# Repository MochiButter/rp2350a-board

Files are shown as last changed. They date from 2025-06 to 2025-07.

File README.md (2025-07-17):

# rp2350a-board
A simple development board featuring the rp2350a microcontroller.

## Changes from the Pico 2

- PICO_DEFAULT_LED_PIN is now IO15
- Flash size increased to 128Mbit
- ESD protection on the usb data wires
- A reset button
- An LDO voltage regulator
- USB-C receptacle

`blink` and `hello_usb` of the examples worked on the board as expected.

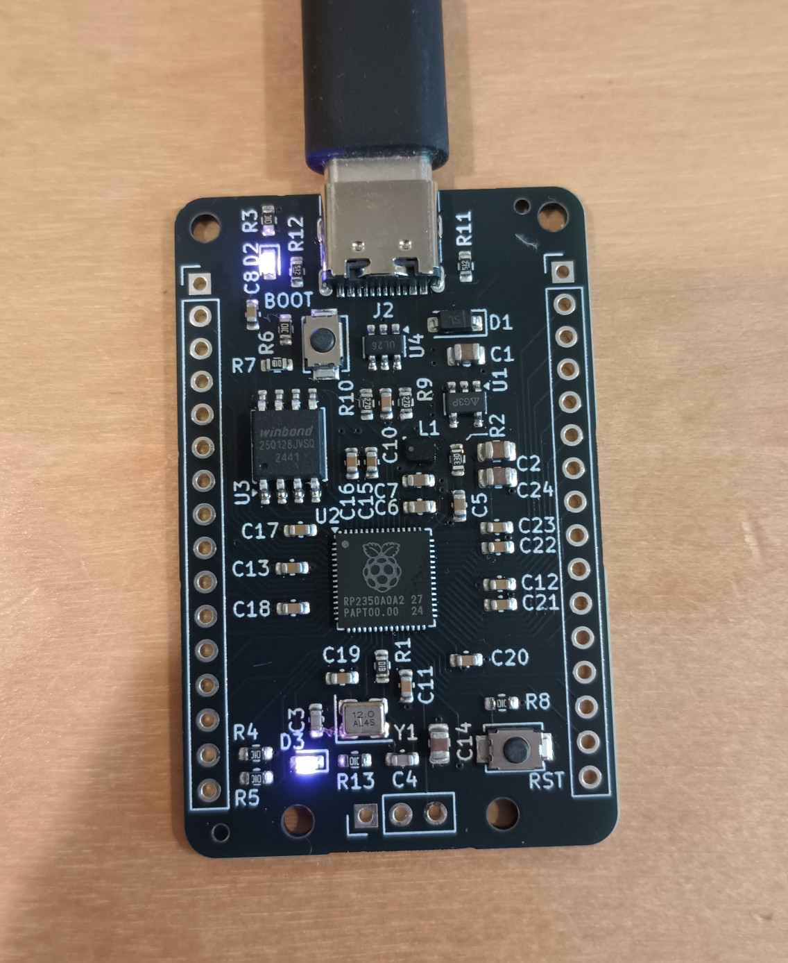
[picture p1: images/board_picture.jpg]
A photo of the board


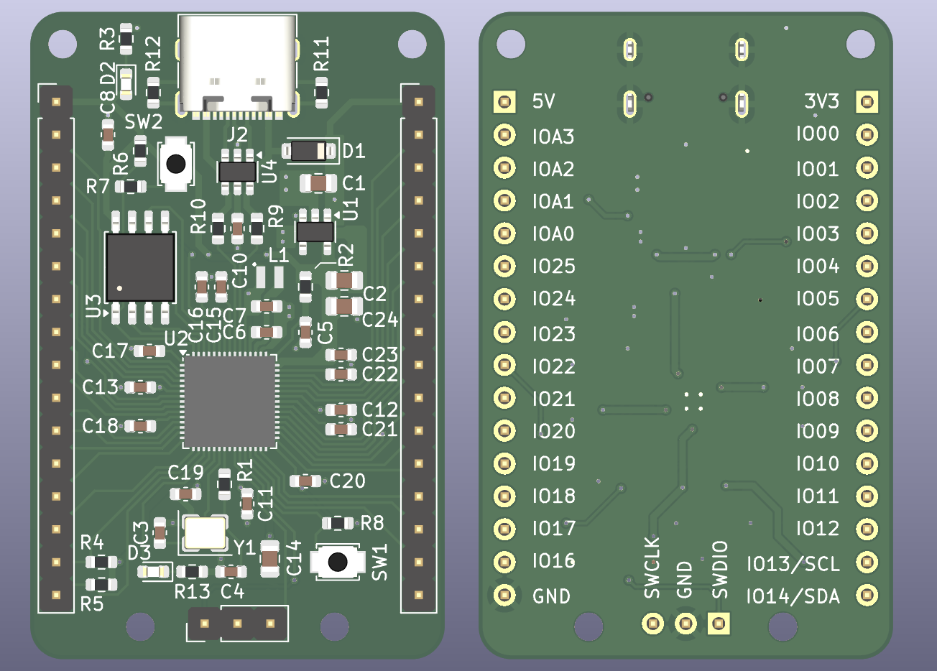
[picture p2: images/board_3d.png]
3D render of the board


Licensed under CERN-OHL-P v2 or later

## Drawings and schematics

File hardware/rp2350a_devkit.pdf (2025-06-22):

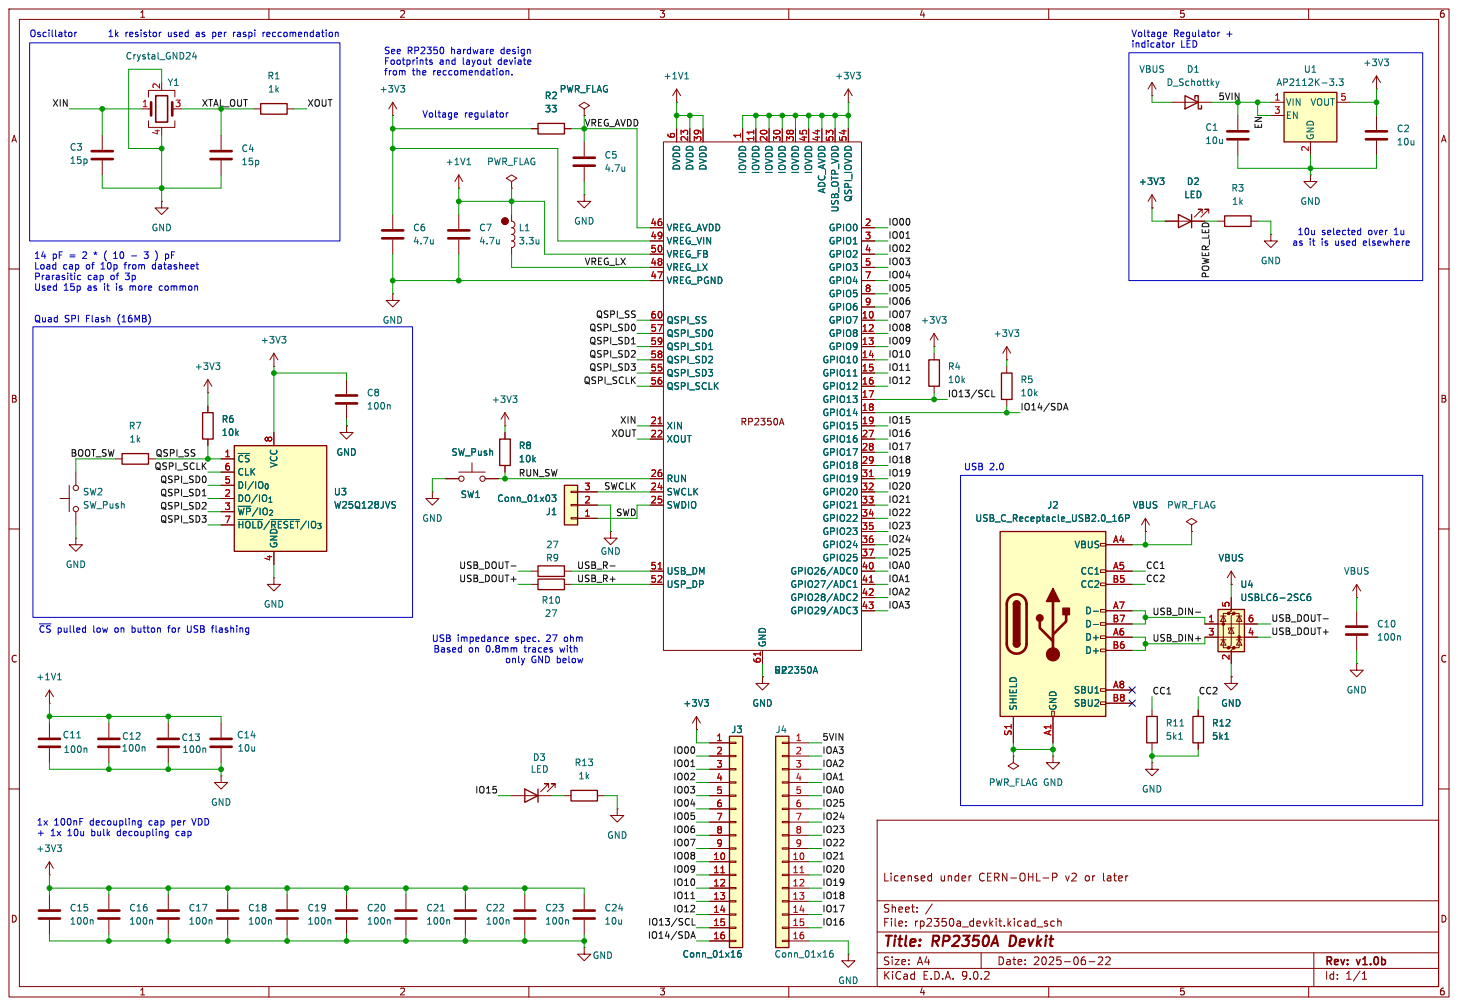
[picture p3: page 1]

1 IOVDD 11 GND 61 IOVDD 20 IOVDD 30 IOVDD 38 IOVDD 45 ADC_AVDD 44 USB_OTP_VDD 53 QSPI_IOVDD 54 GPIO0 2 GPIO1 3 GPIO2 4 GPIO3 5 GPIO4 7 GPIO5 8 GPIO6 9 GPIO7 10 GPIO8 12 GPIO9 13 GPIO10 14 GPIO11 15 GPIO12 16 GPIO13 17 GPIO14 18 GPIO15 19 GPIO16 27 GPIO17 28 GPIO18 29 GPIO19 31 GPIO20 32 GPIO21 33 GPIO22 34 GPIO23 35 GPIO24 36 GPIO25 37 GPIO26/ADC0 40 GPIO27/ADC1 41 GPIO28/ADC2 42 GPIO29/ADC3 43 U2 RP2350A GND

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

as it is used elsewhere

~{CS}pulled low on button for USB flashing

Based on 0.8mm traces with

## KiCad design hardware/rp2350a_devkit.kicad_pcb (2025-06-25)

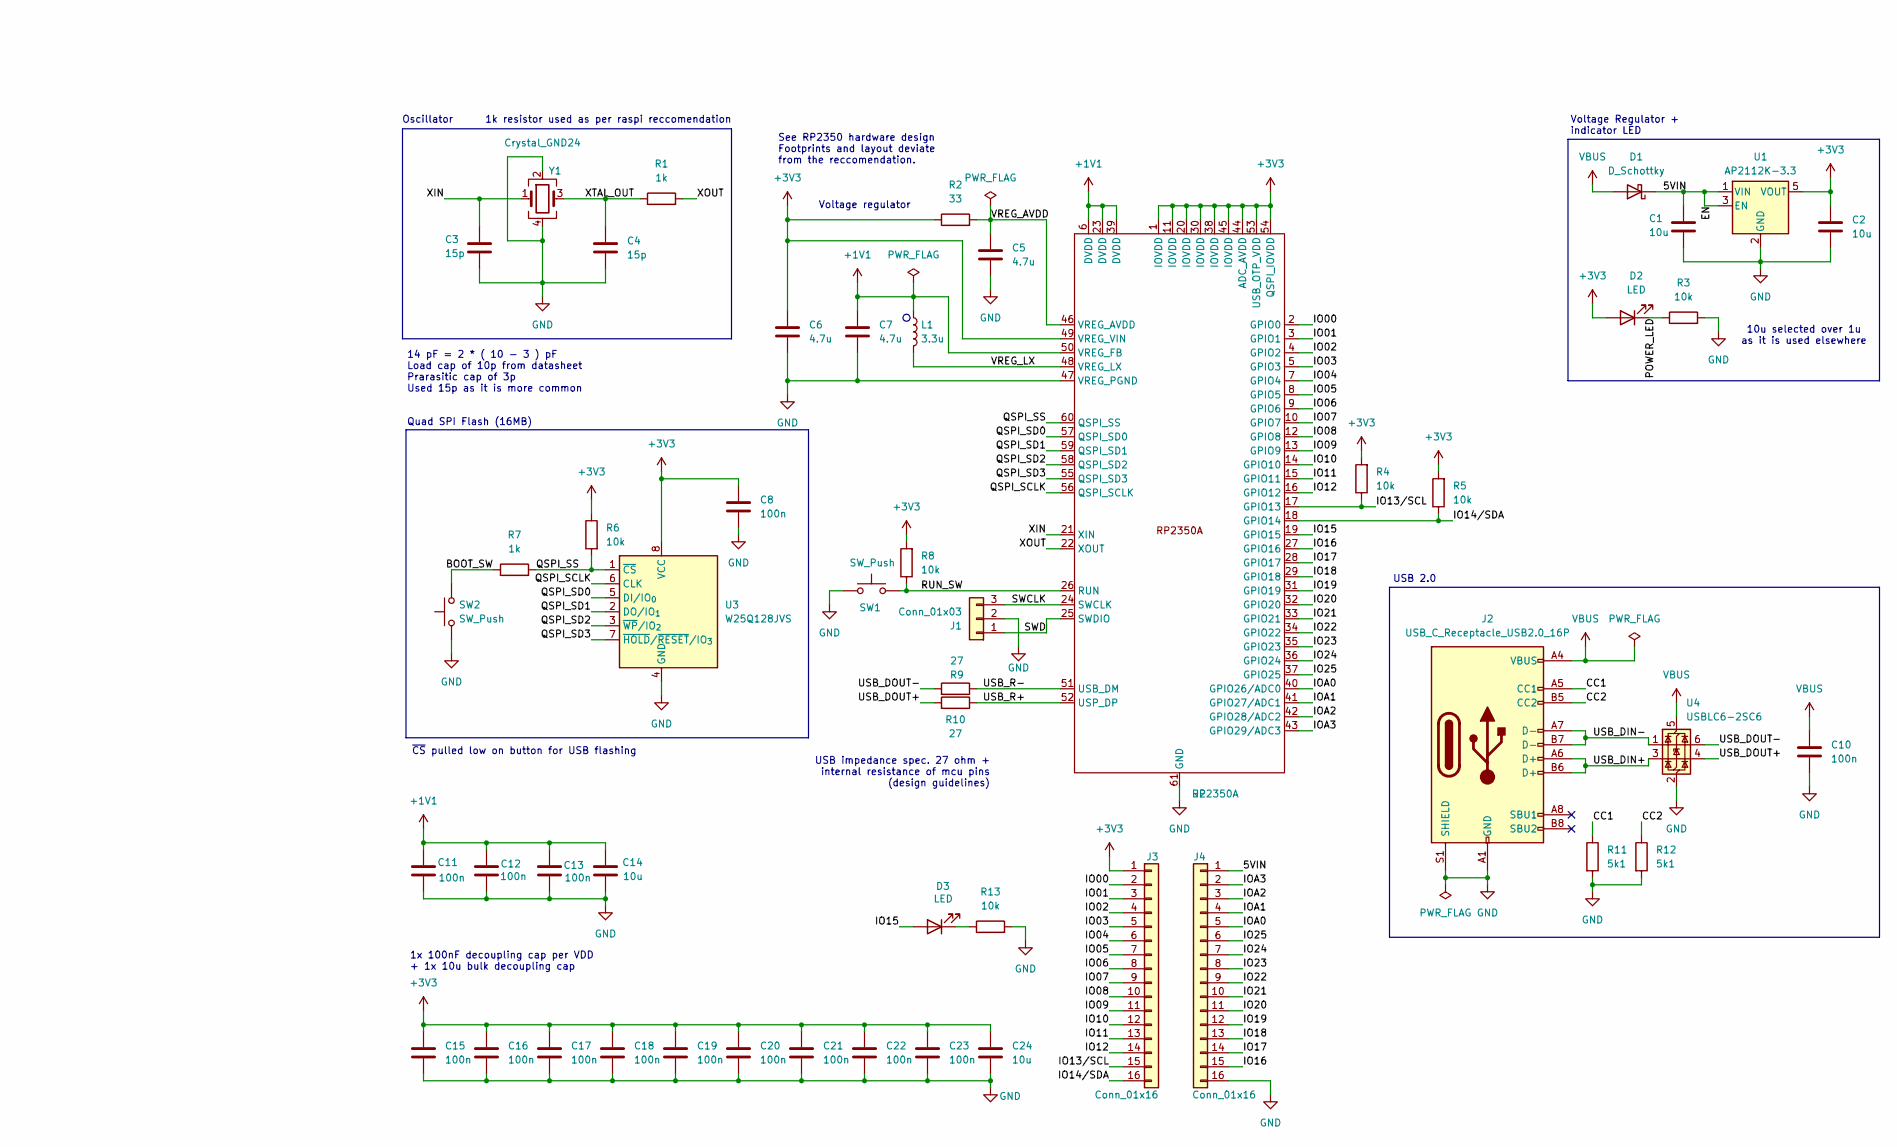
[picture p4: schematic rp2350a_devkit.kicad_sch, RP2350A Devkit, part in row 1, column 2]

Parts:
C1, C2, C14, C24: 10u; C_0805_2012Metric
C3, C4: 15p; C_0603_1608Metric
C5, C6, C7: 4.7u; C_0603_1608Metric
C8, C10, C11, C12, C13, C15, C16, C17, C18, C19, C20, C21, C22, C23: 100n; C_0603_1608Metric
D1: D_Schottky; D_SOD-123; LCSC PN C64885
D2, D3: LED; LED_0603_1608Metric
H1, H2, H3, H4: MountingHole; MountingHole_2.2mm_M2
J1: Conn_01x03; PinHeader_1x03_P2.54mm_Vertical
J2: USB_C_Receptacle_USB2.0_16P; USB_C_Receptacle_G-Switch_GT-USB-7010ASV; LCSC PN C2988369
J3, J4: Conn_01x16; PinHeader_1x16_P2.54mm_Vertical
L1: 3.3u; AOTA-B201610S3R3-101-T; LCSC PN C42411119
R1, R7: 1k; R_0603_1608Metric
R2: 33; R_0603_1608Metric
R3, R4, R5, R6, R8, R13: 10k; R_0603_1608Metric
R9, R10: 27; R_0603_1608Metric
R11, R12: 5k1; R_0603_1608Metric
SW1, SW2: SW_Push; TS-1088-AR02016; LCSC PN C720477
U1: AP2112K-3.3; SOT-23-5; LCSC PN C51118
U2: RP2350A; QFN-60-1EP_7x7mm_P0.4mm_EP3.4x3.4mm; LCSC PN C42411118
U3: W25Q128JVS; SOIC-8_5.3x5.3mm_P1.27mm; LCSC PN C113767
U4: USBLC6-2SC6; SOT-23-6; LCSC PN C7519
Y1: Crystal_GND24; Crystal_SMD_3225-4Pin_3.2x2.5mm; LCSC PN C20625731

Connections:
+1V1: C7.1, C11.1, C12.1, C13.1, C14.1, L1.1, U2.6 (DVDD), U2.23 (DVDD), U2.39 (DVDD), U2.50 (VREG_FB)
+3V3: C2.1, C6.1, C8.1, C15.1, C16.1, C17.1, C18.1, C19.1, C20.1, C21.1, C22.1, C23.1, C24.1, D2.2 (A), J3.1, R2.1, R4.2, R5.2, R6.1, R8.2, U1.5 (VOUT), U2.1 (IOVDD), U2.11 (IOVDD), U2.20 (IOVDD), U2.30 (IOVDD), U2.38 (IOVDD), U2.44 (ADC_AVDD), U2.45 (IOVDD), U2.49 (VREG_VIN), U2.53 (USB_OTP_VDD), U2.54 (QSPI_IOVDD), U3.8 (VCC)
/5VIN: C1.1, D1.1 (K), J4.1, U1.1 (VIN), U1.3 (EN)
/BOOT_SW: R7.1, SW2.1; also elsewhere on the board
/CC1: J2.A5 (CC1), R11.1
/CC2: J2.B5 (CC2), R12.1
/IO00: J3.2, U2.2 (GPIO0)
/IO01: J3.3, U2.3 (GPIO1)
/IO02: J3.4, U2.4 (GPIO2)
/IO03: J3.5, U2.5 (GPIO3)
/IO04: J3.6, U2.7 (GPIO4)
/IO05: J3.7, U2.8 (GPIO5)
/IO06: J3.8, U2.9 (GPIO6)
/IO07: J3.9, U2.10 (GPIO7)
/IO08: J3.10, U2.12 (GPIO8)
/IO09: J3.11, U2.13 (GPIO9)
/IO10: J3.12, U2.14 (GPIO10)
/IO11: J3.13, U2.15 (GPIO11)
/IO12: J3.14, U2.16 (GPIO12)
/IO13/SCL: J3.15, R4.1, U2.17 (GPIO13)
/IO14/SDA: J3.16, R5.1, U2.18 (GPIO14)
/IO15: D3.2 (A), U2.19 (GPIO15)
/IO16: J4.15, U2.27 (GPIO16)
/IO17: J4.14, U2.28 (GPIO17)
/IO18: J4.13, U2.29 (GPIO18)
/IO19: J4.12, U2.31 (GPIO19)
/IO20: J4.11, U2.32 (GPIO20)
/IO21: J4.10, U2.33 (GPIO21)
/IO22: J4.9, U2.34 (GPIO22)
/IO23: J4.8, U2.35 (GPIO23)
/IO24: J4.7, U2.36 (GPIO24)
/IO25: J4.6, U2.37 (GPIO25)
/IOA0: J4.5, U2.40 (GPIO26/ADC0)
/IOA1: J4.4, U2.41 (GPIO27/ADC1)
/IOA2: J4.3, U2.42 (GPIO28/ADC2)
/IOA3: J4.2, U2.43 (GPIO29/ADC3)
/POWER_LED: D2.1 (K), R3.1
/QSPI_SCLK: U2.56 (QSPI_SCLK), U3.6 (CLK)
/QSPI_SD0: U2.57 (QSPI_SD0), U3.5 (DI/IO_{0})
/QSPI_SD1: U2.59 (QSPI_SD1), U3.2 (DO/IO_{1})
/QSPI_SD2: U2.58 (QSPI_SD2), U3.3 (~WP/IO_{2})
/QSPI_SD3: U2.55 (QSPI_SD3), U3.7 (~HOLD/~RESET/IO_{3})
/QSPI_SS: R6.2, R7.2, U2.60 (QSPI_SS), U3.1 (~CS)
/RUN_SW: R8.1, SW1.1, U2.26 (RUN); also elsewhere on the board
/SWCLK: J1.3, U2.24 (SWCLK)
/SWD: J1.1, U2.25 (SWDIO)
/USB_DIN+: J2.A6 (D+), J2.B6 (D+), U4.3 (I/O2)
/USB_DIN-: J2.A7 (D-), J2.B7 (D-), U4.1 (I/O1)
/USB_DOUT+: R10.2, U4.4 (I/O2)
/USB_DOUT-: R9.2, U4.6 (I/O1)
/USB_R+: R10.1, U2.52 (USP_DP)
/USB_R-: R9.1, U2.51 (USB_DM)
/VREG_AVDD: C5.1, R2.2, U2.46 (VREG_AVDD)
/VREG_LX: L1.2, U2.48 (VREG_LX)
/XIN: C3.1, U2.21 (XIN), Y1.1
/XOUT: R1.2, U2.22 (XOUT)
/XTAL_OUT: C4.1, R1.1, Y1.3
GND: C1.2, C2.2, C3.2, C4.2, C5.2, C6.2, C7.2, C8.2, C10.2, C11.2, C12.2, C13.2, C14.2, C15.2, C16.2, C17.2, C18.2, C19.2, C20.2, C21.2, C22.2, C23.2, C24.2, J1.2, J2.A1 (GND), J2.A12 (GND), J2.B1 (GND), J2.B12 (GND), J2.S1 (SHIELD), J4.16, R3.2, R11.2, R12.2, R13.2, SW1.2, SW2.2, U1.2 (GND), U2.47 (VREG_PGND), U2.61 (GND), U3.4 (GND), U4.2 (GND), Y1.2, Y1.4; also elsewhere on the board
unnamed: D3.1 (K), R13.1
VBUS: C10.1, D1.2 (A), J2.A4 (VBUS), J2.A9 (VBUS), J2.B4 (VBUS), J2.B9 (VBUS), U4.5 (VBUS)

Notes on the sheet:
10u selected over 1u as it is used elsewhere
Quad SPI Flash (16MB)
1x 100nF decoupling cap per VDD + 1x 10u bulk decoupling cap
Voltage regulator
Voltage Regulator + indicator LED
USB 2.0
~{CS} pulled low on button for USB flashing
See RP2350 hardware design Footprints and layout deviate from the reccomendation.
14 pF = 2 * ( 10 - 3 ) pF Load cap of 10p from datasheet Prarasitic cap of 3p Used 15p as it is more common
USB impedance spec. 27 ohm + internal resistance of mcu pins (design guidelines)
Oscillator
1k resistor used as per raspi reccomendation

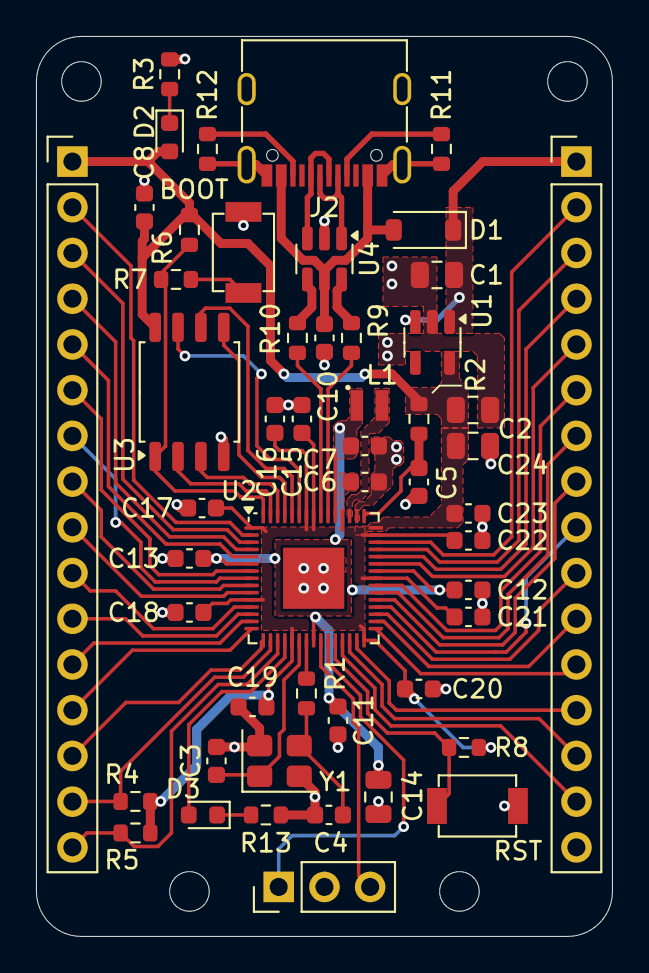
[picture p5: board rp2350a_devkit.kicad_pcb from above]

Board: 2 copper layers, 32.0 x 50.0 mm, 55 parts (0 on the bottom side), 60 nets.

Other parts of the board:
BOOT: SW_Push; TS-1088-AR02016
RST: SW_Push; TS-1088-AR02016

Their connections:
/BOOT_SW: BOOT.1; also elsewhere on the board
/RUN_SW: RST.1; also elsewhere on the board
GND: BOOT.2, RST.2; also elsewhere on the board

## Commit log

2025-06-17 add hw design files
    [rp2350a_devkit.kicad_pcb, rp2350a_devkit.kicad_sch]
2025-06-18 add images and files for v1.0a
    [rp2350a_devkit.kicad_pcb, rp2350a_devkit.kicad_sch]
2025-06-22 re-routed pcb for a better ground plane
    [rp2350a_devkit.kicad_pcb, rp2350a_devkit.kicad_sch]
2025-06-24 update 3d pcb image, fix silkscreen placement and resistor values
    [rp2350a_devkit.kicad_pcb, rp2350a_devkit.kicad_sch]
2025-06-25 changed button footprint
    [rp2350a_devkit.kicad_pcb, rp2350a_devkit.kicad_sch]
2025-07-17 added manufactured board picture
